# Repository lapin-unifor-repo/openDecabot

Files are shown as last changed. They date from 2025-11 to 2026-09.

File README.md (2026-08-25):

# openDecabot
The easiest 3D printed robot you can assemble and program using Wemos D1 Mini Shields and Arduino IDE, powered by ESP8266. Made in Brazil, _Coisado no Ceará_.

**Assembly Instructions on WIKI http://github.com/triwaca/openDecabot/wiki**

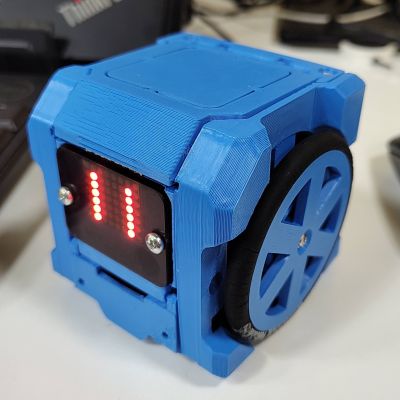
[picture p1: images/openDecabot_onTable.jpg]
Decabot robot on a Table

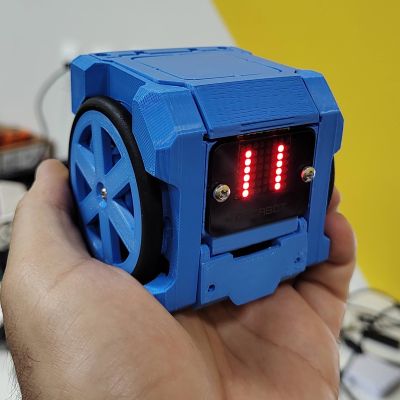
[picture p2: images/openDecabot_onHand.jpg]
A hand holding a Decabot robot


## Hardware
### ESP8266 microcontroler
Open Decabot® uses the ESP8266 controler, in the Wemos Mini form factor, wich allows to use small shields to expand its capacities. In the simplest version, this robot uses a LED matrix shield and a custom connection shield, besides the Wemos D1 mini. The custom shield can be build with a PCB perfboard, a few pin header connections, and some soldering skills. 

By using the Espressif ESP8266 platform, the open Decabot® is nativelly equiped with Wi-Fi capabilities, allowing great IoT experiences, such as remote control and telemetry. 

More information about Wemos platform and a list of main shields available can be found on www.wemos.cc .

### Servo Motors
The open Decabot® robot uses two 360 servo motors to drive its wheels. It's the simplest solution for small robots, since the servo motors didin't require H bridge circuits (they already have those inside!) and can be connected directly to the ESP8266 pins. 

### 3D printed body
You can assemble your Open Decabot® using 3D printed parts. The basic chassis uses only 8 3D printed pieces, and can be assembled using a few screws. The 3D files can be found on **3dPrint** folder. 

### Simple AA batteries for power
Under the open Decabot® you can find a 4 x AA battery support, who can supply up to 6V directly to ESP board. This option simplifies the hardware, since the Wemos Mini board can hold the maxminum 6 volts, lowering the tension to 3 volts. Users can hack the project to use LiIon batteries, combined with the Wemos LiPo Battery Shield (https://www.wemos.cc/en/latest/d1_mini_shield/battery.html) for charging and step up the voltage to 5 volts. 

### Easy access to USB ports
There is a hatch at the upper part of the robot who can be used to access the USB port (for firmware/Arduino sketch update), and other wiring and shield needs. 

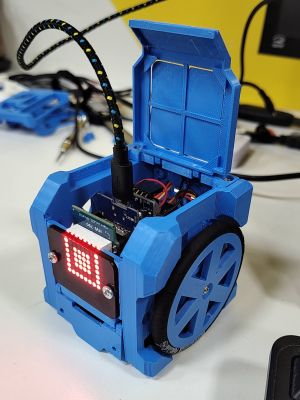
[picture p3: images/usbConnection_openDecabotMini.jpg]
Decabot robot conneceted using USB cable to a computer


### Bill of Materials - BOM
- 1 x Wemos D1 Mini ESP8266 controller
- 2 x Servo 5V 360
- 1 x Wemos LED Matrix Shield
- 1 x custom PCB board (check wiki how to build one) or 1 x Decabot Mini Shield PCB (see **/decabotMiniShield** folder)
- 1 x battery support for 4 x AA
- 1 x acrylic frontface + 2 hallen 3mm screws (optional)
- 7 x screws 3mm, 12mm long
- 2 x rubber o-ring for wheels, size 2" or 50mm (ref: DN50)
- 4 x AA batteries

### Decabot Mini Shield

#### Homemade PDB
Wemos platform does not have a simple shield board to connect servos, so you need a homemade board to use. It's goal is just to simplify the connection between the controller and the motors. A homemade PDB board can be assembled just to connect the main components to the Wemos board: Battery to 5V pin, and servos to D0 and D6 pins, as shown below:

Homemade Decabot Mini PCB

Homemade PCB circuit

#### Buy the Decabot Shield

Help funding this project by buying our dedicated shield. It is the easiest way to enjoy all the possibilities of your Open Decabot Robot!

- Easy access to Servo connections
- On-off switch
- Included buzzer for sounds
- Easy connection for extra sensors, such as line-folowing sensors
- Dedicated connection to Gyroscope/Accelerometer, for mapping projects
- Dedicated connection to I2C modules, such as OLED displays, distance sensors, RGB sensors and RFID/NFC sensors

Homemade PCB circuit

More information about commercial partnership on WIKI soon.

## Arduino Codes

The Arduino sketches can be found on **/ArduinoSketch** folder. You can simply copy this folder inside your Arduino folder on your computer, and open the `.ino` files. 

Remember that Decabot platform is based on `ESP8266` chip, in Wemos D1 Mini form factor. Your Arduino IDE must be proper set to manage ESP8266 family. To se if it is ready, go to `Tools` menu, then `Boards`, and look for `ESP8266 boards`. You must find `Wemos D1 Mini` there. If not, google for _installing ESP8266 on Arduino IDE_.

Some sketches uses libraries who must be installed before. See instructions on each sketch how to proceed. 

## 3D project source
The 3D source project was all designed on Tinkercad (yes!), and can be forked using the link below:
[https://www.tinkercad.com/things/cXxCpU8HWDP-opendecabot-mini-v13](https://www.tinkercad.com/things/cXxCpU8HWDP-opendecabot-mini-v13)

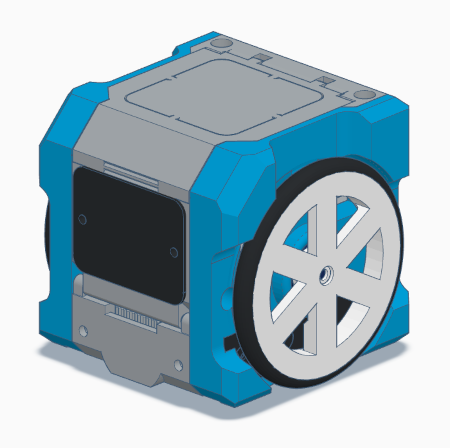
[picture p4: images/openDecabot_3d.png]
Decabot robot on Tinkercad


## Decabot® Trade Mark
Besides this project is open source, the Decabot® name is a registered trademark from Decano Kits Company, and should not be used without proper consent. 

## Open Source Licenses

Open Decabot® project is licensed under CC BY-NC-SA 4.0. You are free to:

- Share — copy and redistribute the material in any medium or format
- Adapt — remix, transform, and build upon the material

Under the following terms:

- Attribution — You must give appropriate credit , provide a link to the license, and indicate if changes were made . You may do so in any reasonable manner, but not in any way that suggests the licensor endorses you or your use.
- NonCommercial — You may not use the material for commercial purposes .
- ShareAlike — If you remix, transform, or build upon the material, you must distribute your contributions under the same license as the original.

Creative Commons License By NC SA https://creativecommons.org/licenses/by-nc-sa/4.0/

See more details at [https://github.com/triwaca/openDecabot/blob/main/LICENSE.md](https://github.com/triwaca/openDecabot/blob/main/LICENSE.md)

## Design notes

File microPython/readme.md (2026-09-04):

# MicroPython no openDecabot
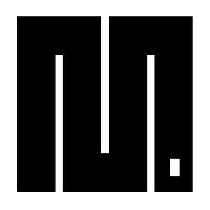
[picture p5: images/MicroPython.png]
MicroPython Logo


Para o uso do microPython no openDecabot estmaos escolhendo unificar os tutoriais com a microcotroladora **ESP32 C3**. Apesar de termos tido sucesso também com o Wemos D1 Mini, a plataforma ESP32, com WiFi e Bluetooth aumentam as possibilidades de uso, além da maior capacidade de processamento.

A escolha do ESP32 C3 também é feita por questões de didática, já que usar outras plataformas podem trazer chaetações e problemas com drivers, especialmente placas que usam o chip CH341 para a porta USB e sua infinita chatice com o Windows de ficar instalando e reinstalando os drivers (esse problema não ocorre em quem usa Linux). 
## Vantagens do microPython ao invés da programação Arduino C
A implementação do micrpPython traz muitas vantagens para quem está aprendendo. Obviamente para projetos complexos, que exigem o maior desempenho possível, recomenda-se escrever os códigos em C direto. Mas para quem está iniciando aqui vão alguns pontos a se tocar:
### A controladora funciona como um disco com diferentes arquivos
Sua microcontroladora ESP32 C3 (ou outra qualquer) funciona como um disco cheio de arquivos .py para usar. Inclusive com pastas para organizar, e com arquivos especiais para executar assim que a placa é ligada (`boot.py`). Ou seja, sua placa pode tornar-se um repositório de códigos que você vem escrevendo e testando sempre a mão, para reutilizar. 
### Só se grava a firmware uma vez
O processo de gravar o firmware inteiro como se faz na IDE do Arduino é muito lento, arriscado e pouco prático. No microPython você só vai acrescentando novos arquivos .py a sua coleção! E ao conectar seu robô/placa na IDE você pode chamar diferentes arquivos para executar. Isso permite, por exemplo que eu tenha diferentes configurações gravadas de um robô, por exemplo, que podem ser carregadas para diferentes competições. 
### Terminal Python REPL
O python tem um terminal de comandos que podem ser executados diretamente. É o chamado REPL:
-   **Read (Ler):** Recebe o código digitado pelo usuário.

-   **Eval (Avaliar/Executar):** Processa e executa essa instrução.

-   **Print (Imprimir):** Mostra o resultado da execução no terminal.

-   **Loop (Repetir):** Retorna ao estado inicial, aguardando o próximo comando
O estudante pode experimentar comandos no terminal, ver ações, ler sensores ou mover motores diretamente, sem precisar compilar e gravar a firmware. 

## Preparando seu ESP32 C3

Para usar o microPython você precisa gravar uma firmware específica no seu microcontrolador pela primeira vez. Existem várias formas de fazer isso, e você pode buscar outros tutorias mais completos caso deseje. Para nós, o melhor caminho foi:
- Baixar a release mais nova da ESPTOOL: https://github.com/espressif/esptool/releases
- Baixar o arquivo bin da controladora: https://micropython.org/download/
	- No caso do ESP32 C3 o link é esse: https://micropython.org/download/ESP32_GENERIC_C3/
	- Baixe a página até a sessão _Firmware Releases_ para encontrar o arquivo mais novo.
	- Coloque o arquivo .bin baixado **na mesma pasta** do programa ESPTOOL, para facilitar os comandos!
- Colocar a controladora na USB e ver qual porta está:
	- Para isso usamos a IDE do Arduino para verificar qual porta COM (Win) ou /dev (Linux)
- Apagar a FLASH da controladora:
	- WIN (_substitua a porta COM com a sua_): `esptool --port com16 erase_flash`
	- LINUX (_substitua a porta /dev com a sua_):	`.\esptool --port /dev/ttyUSB0 erase_flash`
- Gravar o arquivo bin na flash (_substitua o nome do arquivo pelo que você baixou! Ou use a tecla `TAB` no seu terminal para que ele preencha automaticamente o nome_):
	- WIN (_substitua a porta COM com a sua_): `esptool --port com16 --baud 460800 write-flash --flash_size=detect 0 ESP32_GENERIC_C3-20260824-v1.29.0.bin`
	- Linux (_substitua a porta /dev com a sua_): `esptool --port /dev/ttyUSB0 --baud 460800 write-flash --flash_size=detect 0 ESP32_GENERIC_C3-20260824-v1.29.0.bin`
## Usando um editor para microPython
### Thony, o mais fácil
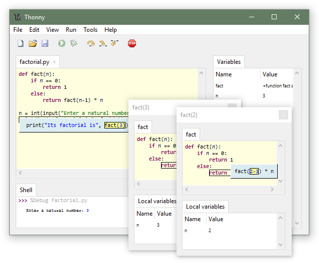
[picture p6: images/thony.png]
Thony Editor Interface


O editor para python Thony é Open Source e bem simples de instalar e usar. Baixe em https://thonny.org/ e instale no seu sistema. Para configurar seu microcontrolador para usar, vá em `Executar > Configurar interpretador` e defina que está usando um **MicroPython (ESP32)** na porta **detectar automaticamente**. Se tudo correr bem, você conseguirá conversar em python com o ESP32 C3 no seu robo openDecabot pelo terminal no canto inferior da tela. Experimente digitar algum comando simples, como 2 + 2, e veja o resultado. Quem estará respondendo será seu robô, e não seu computador.
### ESPIDE, o mais promissor
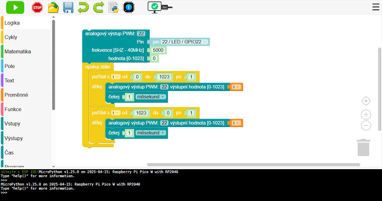
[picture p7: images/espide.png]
ESP IDE interface


O projeto ESP IDE também é Open Source e roda diretamente no navegador. Nele é possível conectar-se à sua microcontroladora diretamente, e usar códigos python ou editor de blocos. Acesse em https://www.espide.eu/en/ .
## Arquivos .py disponíveis
As pastas aqui disponíveis já trazem um conjunto de arquivos .py que funcionam como drivers para diferentes componentes de um openDecabot. Você pode usá-los com qualquer editor, mas iremos experimentar no ESP IDE. Basta usar o editor para copiar esses aquivos para sua microcontroladora.

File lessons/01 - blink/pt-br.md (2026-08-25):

# Piscar um LED (Blink) com o Wemos D1 Mini

Bem-vindos a este guia de introdução prática. Este tutorial foi desenvolvido para capacitar os alunos nas atividades da disciplina de Experimentação Orientada, servindo como base para projetos de robótica open-source, como o *openDecabot*. O objetivo é compreender a estrutura de programação, a pinagem do microcontrolador e a lógica de controle de hardware através da plataforma Wemos D1 Mini, baseada no chip ESP8266.

## 1. Objetivos da Aula

* Configurar o ambiente de desenvolvimento Arduino IDE para o Wemos D1 Mini.
* Compreender o mapeamento de pinos (Pinout) da placa.
* Escrever e carregar um código para controlar o LED embutido (built-in LED).
  
  ## 2. Conhecendo o Hardware: Wemos D1 Mini
  
  O Wemos D1 Mini é uma placa de desenvolvimento compacta com conectividade Wi-Fi nativa, excelente para prototipagem de sistemas embarcados. Um detalhe crucial para iniciantes é o mapeamento dos pinos (GPIO). A numeração impressa na placa (como D1, D2, D4) não corresponde diretamente ao número do GPIO lido internamente pelo chip.
  Neste exercício, utilizaremos o LED azul que já vem soldado na placa. Veja a relação de pinos na tabela abaixo:
  
  | Pino na Placa (Label)                                                                                                                                            | GPIO Interno (ESP8266) | Função e Observações                                                    |
  |:---------------------------------------------------------------------------------------------------------------------------------------------------------------- |:---------------------- |:----------------------------------------------------------------------- |
  | **D4**                                                                                                                                                           | GPIO 2                 | Conectado ao **LED Embutido**. Opera com lógica invertida (Active-LOW). |
  | **Importante:** O LED do Wemos D1 Mini opera em *Active-LOW*. Isso significa que enviar um sinal numérico 0 (LOW) liga o LED, e um sinal 1 (HIGH) desliga o LED. |                        |                                                                         |
  
  ## 3. Materiais Necessários
* 1x Placa Wemos D1 Mini (ESP8266)
* 1x Cabo Micro-USB para transferência de dados
* Computador com a Arduino IDE instalada
  
  ## 4. Preparando a Arduino IDE
1. Abra a Arduino IDE, vá em **Arquivo > Preferências**.

2. No campo de URLs Adicionais para Gerenciadores de Placas, insira o link oficial do pacote ESP8266 e clique em OK.

3. Vá em **Ferramentas > Placa > Gerenciador de Placas...**. Busque por "esp8266" e instale o pacote desenvolvido pela comunidade ESP8266.

4. Após a instalação, vá em **Ferramentas > Placa** e selecione **LOLIN(WEMOS) D1 R2 & mini**.

5. Conecte sua placa ao computador usando o cabo USB e selecione a porta correta em **Ferramentas > Porta**.
   
   ## 5. O Código-Fonte (Sketch)
   
   Copie o código abaixo para a sua IDE. Leia os comentários atentamente para entender o fluxo de execução do programa.
   
   ```cpp
   /*
   Laboratório Lapin - Introdução a Microcontroladores
   Projeto: Blink (Piscar LED) com Wemos D1 Mini
   */
   // O pino D4 (GPIO2) possui o LED azul embutido na placa
   const int ledPin = D4; 
   void setup() {
       // Configura o pino do LED como uma saída (OUTPUT)
       pinMode(ledPin, OUTPUT);
   }
   void loop() {
       // Liga o LED (lembre-se: Active-LOW, então LOW liga o LED)
       digitalWrite(ledPin, LOW);  
   
       // Aguarda 1000 milissegundos (1 segundo)
       delay(1000);                      
   
       // Desliga o LED (HIGH desliga)
       digitalWrite(ledPin, HIGH); 
   
       // Aguarda mais 1 segundo antes de reiniciar o ciclo
       delay(1000);                      
   }
   ```
   
   ## 6. Compilando e Carregando
* Clique no botão **Verificar** (ícone de V) no canto superior esquerdo para compilar o código e verificar se há erros de sintaxe.
* Clique no botão **Carregar** (ícone de Seta para a direita). A IDE irá compilar e transferir o firmware para a memória flash do Wemos D1 Mini.
* Assim que aparecer a mensagem de transferência concluída na parte inferior da tela, o LED azul da sua placa começará a piscar em intervalos de 1 segundo!
  
  ## 7. Desafio Prático
  
  Agora que o código base está funcionando, tente modificar a frequência das piscadas. Experimente fazer o LED piscar rapidamente como um estrobo (exemplo: 100ms ligado, 100ms desligado), ou criar um padrão assimétrico alternando entre tempos longos e curtos na função `delay()`. Esses testes são essenciais para dominar a lógica de tempo em sistemas embarcados antes de avançarmos para o controle de motores e leitura de sensores.

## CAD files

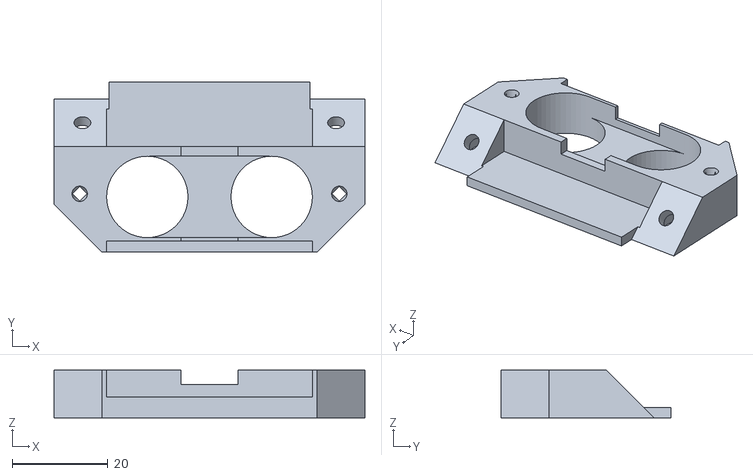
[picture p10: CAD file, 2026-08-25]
3dPrint/accessories/ultrassonic_OpenDecabotMINIV1.stl
65.0 x 35.5 x 10.0

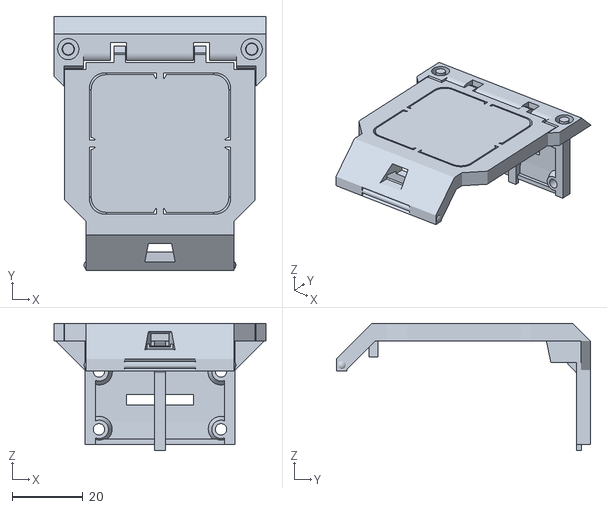
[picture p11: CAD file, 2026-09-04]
3dPrint/top_OpenDecabotMINIV1.stl
60.0 x 72.0 x 36.0

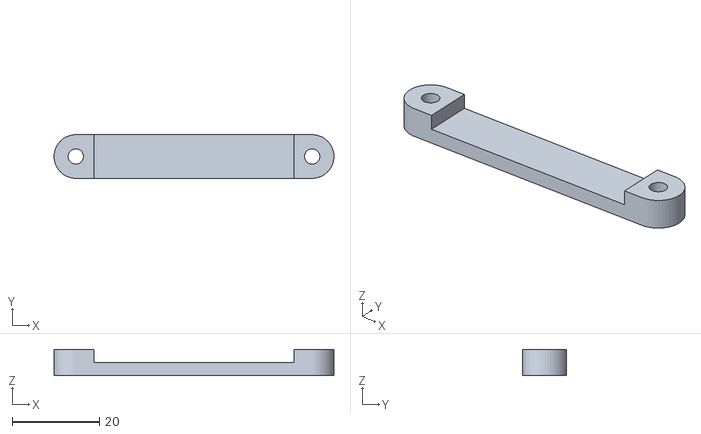
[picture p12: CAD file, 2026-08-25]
3dPrint/accessories/ultrassonicSupport_OpenDecabotMINIV1.stl
64.2 x 10.0 x 6.00

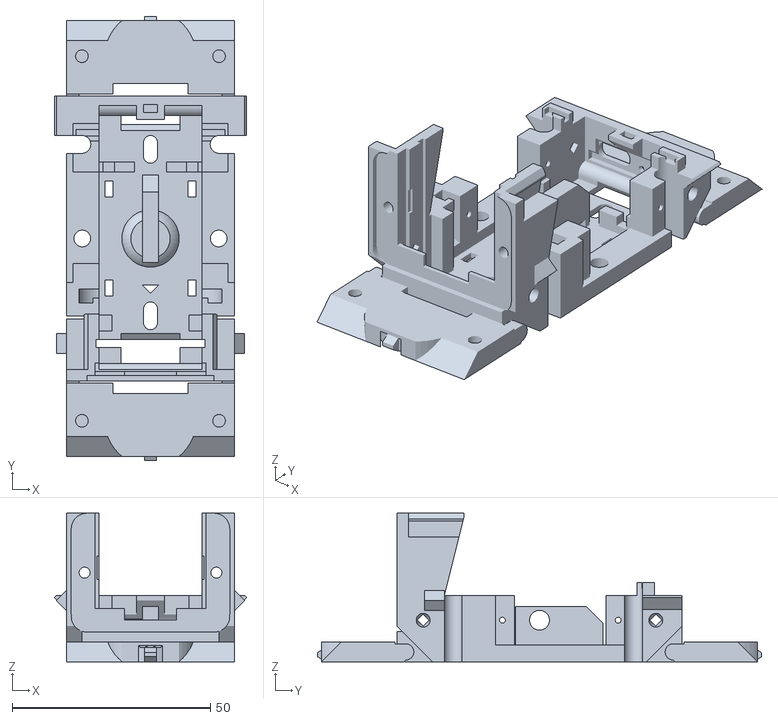
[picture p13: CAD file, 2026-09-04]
3dPrint/bottom_OpenDecabotMINIV1.stl
48.5 x 112.0 x 37.5

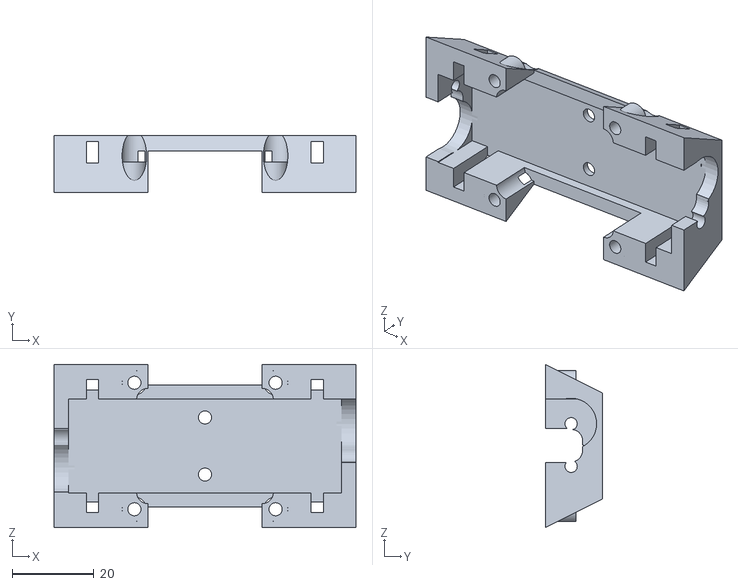
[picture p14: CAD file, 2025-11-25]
3dPrint/accessories/bucketMotors_OpenDecabotMINIV1.stl
74.0 x 14.0 x 40.0

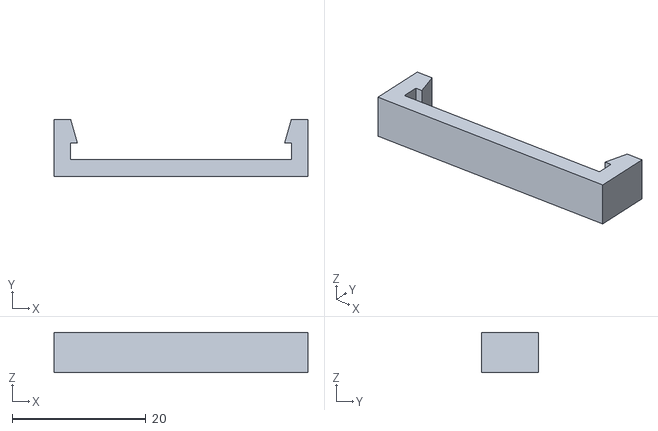
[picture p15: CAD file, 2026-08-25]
3dPrint/boardguide_OpenDecabotMINIV1.stl
38.0 x 8.50 x 6.00

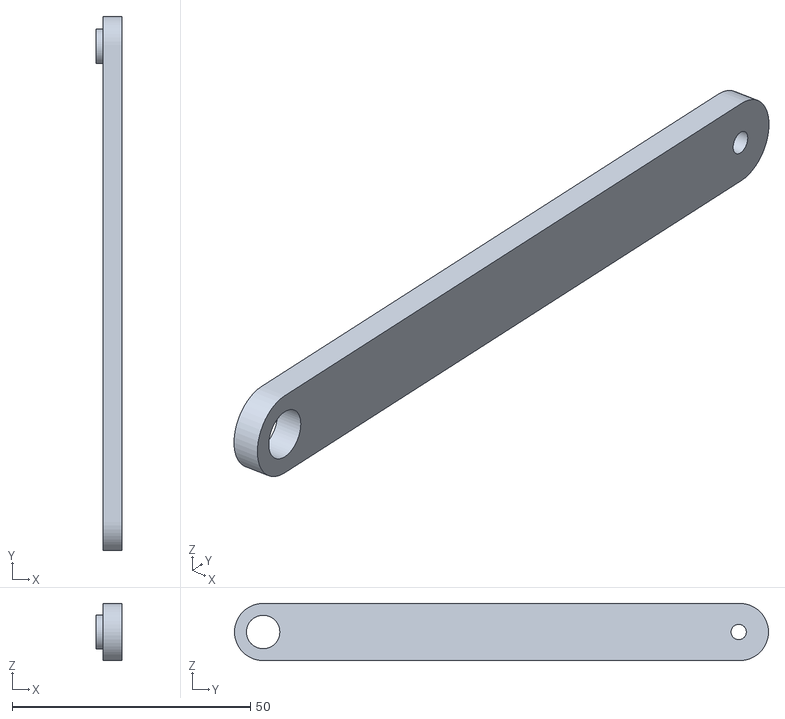
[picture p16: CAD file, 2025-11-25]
3dPrint/accessories/bucketLeft_OpenDecabotMINIV1.stl
5.39 x 112.0 x 12.0

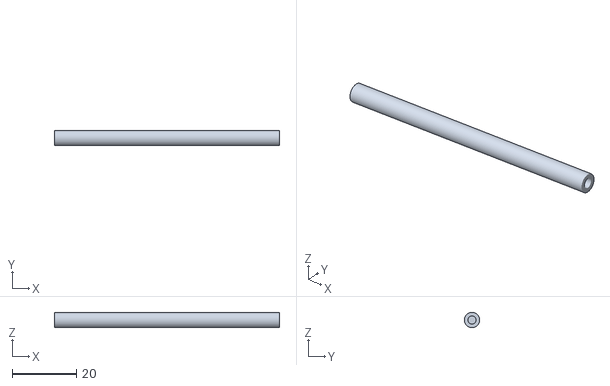
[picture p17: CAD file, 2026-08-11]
3dPrint/shaft_OpenDecabotMINIV1.stl
70.0 x 4.80 x 4.80

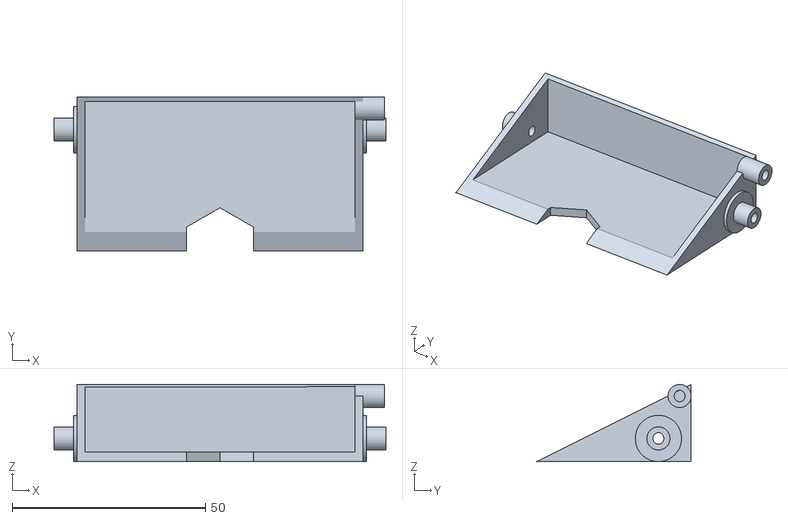
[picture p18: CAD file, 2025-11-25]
3dPrint/accessories/bucketFront_OpenDecabotMINIV1.stl
86.0 x 40.0 x 20.0

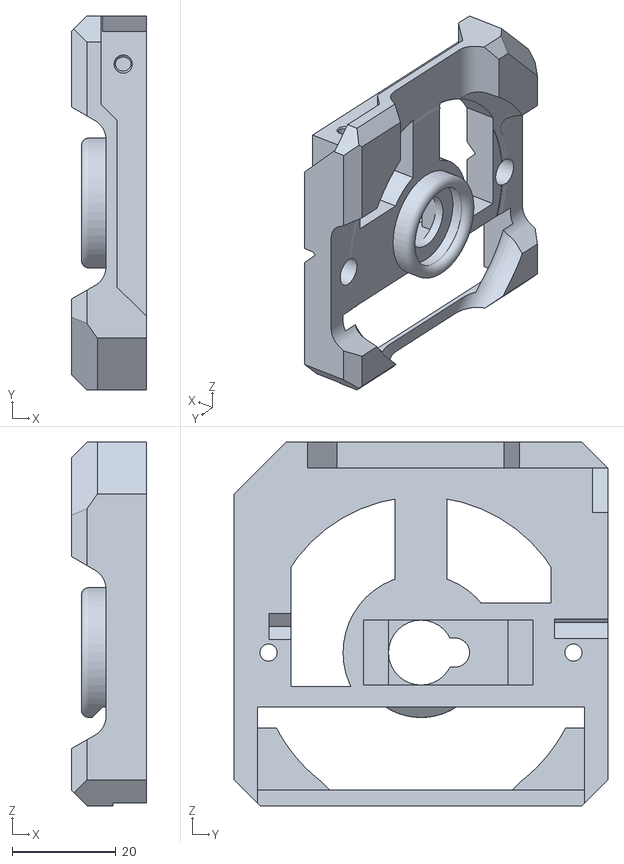
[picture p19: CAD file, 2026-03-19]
3dPrint/right_OpenDecabotMINIV1.stl
14.5 x 72.0 x 70.0

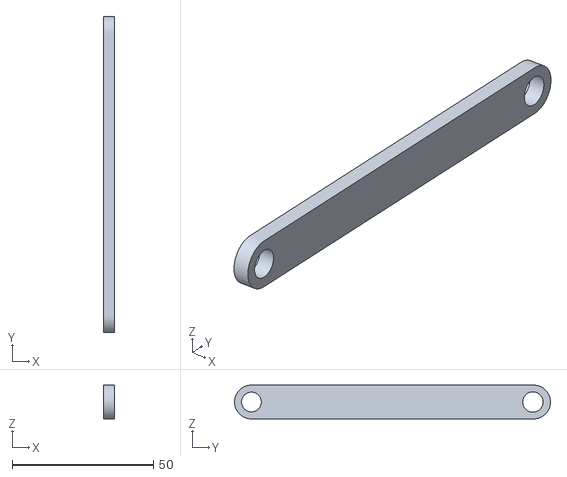
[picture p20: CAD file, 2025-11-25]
3dPrint/accessories/bucketRight_OpenDecabotMINIV1.stl
4.00 x 112.0 x 12.0

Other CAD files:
3dPrint/left_OpenDecabotMINIV1.stl

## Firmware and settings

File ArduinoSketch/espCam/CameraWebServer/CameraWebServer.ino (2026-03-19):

#include "esp_camera.h"
#include <WiFi.h>

//
// WARNING!!! PSRAM IC required for UXGA resolution and high JPEG quality
//            Ensure ESP32 Wrover Module or other board with PSRAM is selected
//            Partial images will be transmitted if image exceeds buffer size
//
//            You must select partition scheme from the board menu that has at least 3MB APP space.
//            Face Recognition is DISABLED for ESP32 and ESP32-S2, because it takes up from 15
//            seconds to process single frame. Face Detection is ENABLED if PSRAM is enabled as well

// ===================
// Select camera model
// ===================
//#define CAMERA_MODEL_WROVER_KIT // Has PSRAM
//#define CAMERA_MODEL_ESP_EYE  // Has PSRAM
//#define CAMERA_MODEL_ESP32S3_EYE // Has PSRAM
//#define CAMERA_MODEL_M5STACK_PSRAM // Has PSRAM
//#define CAMERA_MODEL_M5STACK_V2_PSRAM // M5Camera version B Has PSRAM
//#define CAMERA_MODEL_M5STACK_WIDE // Has PSRAM
//#define CAMERA_MODEL_M5STACK_ESP32CAM // No PSRAM
//#define CAMERA_MODEL_M5STACK_UNITCAM // No PSRAM
//#define CAMERA_MODEL_M5STACK_CAMS3_UNIT  // Has PSRAM
#define CAMERA_MODEL_AI_THINKER // Has PSRAM
//#define CAMERA_MODEL_TTGO_T_JOURNAL // No PSRAM
//#define CAMERA_MODEL_XIAO_ESP32S3 // Has PSRAM
// ** Espressif Internal Boards **
//#define CAMERA_MODEL_ESP32_CAM_BOARD
//#define CAMERA_MODEL_ESP32S2_CAM_BOARD
//#define CAMERA_MODEL_ESP32S3_CAM_LCD
//#define CAMERA_MODEL_DFRobot_FireBeetle2_ESP32S3 // Has PSRAM
//#define CAMERA_MODEL_DFRobot_Romeo_ESP32S3 // Has PSRAM
#include "camera_pins.h"

// ===========================
// Enter your WiFi credentials
// ===========================
const char *ssid = "skynet";
const char *password = "82at1nc&";

void startCameraServer();
void setupLedFlash(int pin);

void setup() {
  Serial.begin(115200);
  Serial.setDebugOutput(true);
  Serial.println();

  camera_config_t config;
  config.ledc_channel = LEDC_CHANNEL_0;
  config.ledc_timer = LEDC_TIMER_0;
  config.pin_d0 = Y2_GPIO_NUM;
  config.pin_d1 = Y3_GPIO_NUM;
  config.pin_d2 = Y4_GPIO_NUM;
  config.pin_d3 = Y5_GPIO_NUM;
  config.pin_d4 = Y6_GPIO_NUM;
  config.pin_d5 = Y7_GPIO_NUM;
  config.pin_d6 = Y8_GPIO_NUM;
  config.pin_d7 = Y9_GPIO_NUM;
  config.pin_xclk = XCLK_GPIO_NUM;
  config.pin_pclk = PCLK_GPIO_NUM;
  config.pin_vsync = VSYNC_GPIO_NUM;
  config.pin_href = HREF_GPIO_NUM;
  config.pin_sccb_sda = SIOD_GPIO_NUM;
  config.pin_sccb_scl = SIOC_GPIO_NUM;
  config.pin_pwdn = PWDN_GPIO_NUM;
  config.pin_reset = RESET_GPIO_NUM;
  config.xclk_freq_hz = 20000000;
  config.frame_size = FRAMESIZE_UXGA;
  config.pixel_format = PIXFORMAT_JPEG;  // for streaming
  //config.pixel_format = PIXFORMAT_RGB565; // for face detection/recognition
  config.grab_mode = CAMERA_GRAB_WHEN_EMPTY;
  config.fb_location = CAMERA_FB_IN_PSRAM;
  config.jpeg_quality = 12;
  config.fb_count = 1;

  // if PSRAM IC present, init with UXGA resolution and higher JPEG quality
  //                      for larger pre-allocated frame buffer.
  if (config.pixel_format == PIXFORMAT_JPEG) {
    if (psramFound()) {
      config.jpeg_quality = 10;
      config.fb_count = 2;
      config.grab_mode = CAMERA_GRAB_LATEST;
    } else {
      // Limit the frame size when PSRAM is not available
      config.frame_size = FRAMESIZE_SVGA;
      config.fb_location = CAMERA_FB_IN_DRAM;
    }
  } else {
    // Best option for face detection/recognition
    config.frame_size = FRAMESIZE_240X240;
#if CONFIG_IDF_TARGET_ESP32S3
    config.fb_count = 2;
#endif
  }

#if defined(CAMERA_MODEL_ESP_EYE)
  pinMode(13, INPUT_PULLUP);
  pinMode(14, INPUT_PULLUP);
#endif

  // camera init
  esp_err_t err = esp_camera_init(&config);
  if (err != ESP_OK) {
    Serial.printf("Camera init failed with error 0x%x", err);
    return;
  }

  sensor_t *s = esp_camera_sensor_get();
  // initial sensors are flipped vertically and colors are a bit saturated
  if (s->id.PID == OV3660_PID) {
    s->set_vflip(s, 1);        // flip it back
    s->set_brightness(s, 1);   // up the brightness just a bit
    s->set_saturation(s, -2);  // lower the saturation
  }
  // drop down frame size for higher initial frame rate
  if (config.pixel_format == PIXFORMAT_JPEG) {
    s->set_framesize(s, FRAMESIZE_QVGA);
  }

#if defined(CAMERA_MODEL_M5STACK_WIDE) || defined(CAMERA_MODEL_M5STACK_ESP32CAM)
  s->set_vflip(s, 1);
  s->set_hmirror(s, 1);
#endif

#if defined(CAMERA_MODEL_ESP32S3_EYE)
  s->set_vflip(s, 1);
#endif

// Setup LED FLash if LED pin is defined in camera_pins.h
#if defined(LED_GPIO_NUM)
  setupLedFlash(LED_GPIO_NUM);
#endif

  WiFi.begin(ssid, password);
  WiFi.setSleep(false);

  while (WiFi.status() != WL_CONNECTED) {
    delay(500);
    Serial.print(".");
  }
  Serial.println("");
  Serial.println("WiFi connected");

  startCameraServer();

  Serial.print("Camera Ready! Use 'http://");
  Serial.print(WiFi.localIP());
  Serial.println("' to connect");
}

void loop() {
  // Do nothing. Everything is done in another task by the web server
  delay(10000);
}

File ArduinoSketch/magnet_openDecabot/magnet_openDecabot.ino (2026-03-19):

/*
===============================================================================================================
Based on QMC5883LCompass.h Library XYZ Example Sketch
Learn more at [https://github.com/mprograms/QMC5883LCompass]

Release under the GNU General Public License v3
[https://www.gnu.org/licenses/gpl-3.0.en.html]
===============================================================================================================
*/
#include <QMC5883LCompass.h>
#include <Adafruit_GFX.h>       //tested on version 1.11.10
#include <WEMOS_Matrix_GFX.h>   //tested on version 1.4.0

MLED matrix(7); //set intensity=7 (maximum)

QMC5883LCompass compass;

int x, y = 1500;
int maxX,maxY = 0;
int minX,minY = 6000;
int valueX,valueY = 0;

void setup() {
  //
  matrix.setRotation(2);
  Serial.begin(115200);
  compass.setADDR(0x0D); //check yours with I2Cscanner
  compass.init();
  compass.setSmoothing(5,true);  
  Serial.println("iniciando...");
  matrix.clear();
  matrix.drawLine(2,2,5,2, LED_ON);
  matrix.drawLine(2,2,2,5, LED_ON);
  matrix.drawLine(5,2,5,5, LED_ON);
  matrix.drawLine(5,5,2,5, LED_ON);
  matrix.writeDisplay();
  for(int i=0;i<15;i++){
    compass.read();
    delay(250);
  }
}

void loop() {
  // Read compass values
  compass.read();

  // Return XYZ readings
  x = compass.getX();
  y = compass.getY();
  
  //debug?!
  if(minX==0) minX = maxX;

  if(x!=0){
    if(x>maxX) maxX = x;
    if(x<minX) minX = x;
  }
  if(y!=0){
    if(y>maxY) maxY = y;
    if(y<minY) minY = y;
  }

  Serial.print("| " + (String)minX + "\t" + (String)x + "\t" + (String)maxX + " |");
  Serial.print("| " + (String)minY + "\t" + (String)y + "\t" + (String)maxY + " |");

  //wait values to stabilize before calculus
  if(millis()>4000) valueX = map(x,minX,maxX,7,0);
  if(millis()>4000) valueY = map(y,minY,maxY,7,0);
  
  Serial.print("X: ");
  Serial.print(valueX);
  Serial.print(" Y: ");
  Serial.print(valueY);
  Serial.println();

  matrix.clear();
  //vertical
  matrix.drawLine(valueX,0,valueX,7, LED_ON);
  //horizontal
  matrix.drawLine(0,valueY,7,valueY, LED_ON);
  matrix.writeDisplay();
  delay(250);
}

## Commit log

2025-11-25 New bucket accessory
    [bucketFront_OpenDecabotMINIV1.stl, bucketLeft_OpenDecabotMINIV1.stl, bucketMotors_OpenDecabotMINIV1.stl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]
2026-03-19 Updated 3D solved issue #1 solved issue #2
    [bottom_OpenDecabotMINIV1.stl, left_OpenDecabotMINIV1.stl, right_OpenDecabotMINIV1.stl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]
2026-03-31 Update decabot_webControler.ino
    Included Calibration variable and new function to control motors.
2026-04-14 Urgent update to correct servo control
    [decabot_webControler.ino]
2026-07-24 3D improvements
    [boardguide_OpenDecabotMINIV1.stl, bottom_OpenDecabotMINIV1.stl, ultrassonicSupport_OpenDecabotMINIV1.stl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]
2026-08-11 New compatible with ESP32 C3 and OLED display
    [bottom_OpenDecabotMINIV1.stl, top_OpenDecabotMINIV1.stl]
2026-08-12 Improvements on ESP32 C3 and OLED
    [bottom_OpenDecabotMINIV1.stl, top_OpenDecabotMINIV1.stl]
2026-08-29 Minor ajustments
    [bottom_OpenDecabotMINIV1.stl, top_OpenDecabotMINIV1.stl]
2026-09-03 Enhance readme with images and additional details
    Add images and improve tutorial clarity for ESP32 C3
2026-09-04 Revert "Update bottom_OpenDecabotMINIV1.stl"
    This reverts commit 9e46652487a2dccb07d48ae2475a98fef6c23a4e.
    [bottom_OpenDecabotMINIV1.stl]
